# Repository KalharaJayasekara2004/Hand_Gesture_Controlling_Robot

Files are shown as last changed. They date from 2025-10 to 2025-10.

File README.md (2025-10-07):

# Hand Gesture-Controlled Robot with Gripper Expansion


This is a gesture-controlled robot project using ESP32 and MPU6050 IMU, with a gripper expansion. The robot uses two ESP32 boards for transmitter and receiver communication and comes with STL files for the chassis.

## Features
- Gesture control using MPU6050 IMU
- Gripper mechanism for object manipulation
- ESP32-CAM for wireless video streaming
- Transmitter and receiver using ESP32 boards
- Fully 3D-printable chassis

## Components
- ESP32 boards (x2)
- MPU6050 IMU
- TB6612 FNG motor drivers(x2)
- Gripper expansion
- Servo motor for gripper
- ESP32-cam
- Mecanum wheels(x4)
- TT gear motors(x4)
- 3.7V Li-ion batteries(x3)
- Miscellaneous electronics and mechanical parts
- STL files for chassis

## File Structure
- Code- Arduino sketches for transmitter and receiver
- 3D Files - STL files for 3D printing chassis
- Images - Photos of the assembled robot

## Usage
1. Upload the `Transmitter.ino` sketch to the transmitter ESP32.
2. Upload the `Receiver.ino` sketch to the receiver ESP32.
3. Assemble the robot chassis using the STL files.
4. Connect hardware.
5. Power the ESP32 boards and test gestures.

## Author
- Kalhara Jayasekara
- Electrical and Electronic Engineering Undergraduate | University of Peradeniya

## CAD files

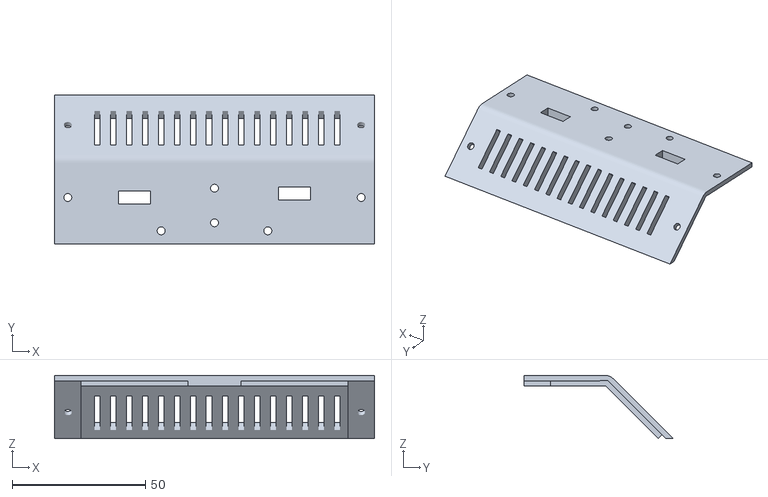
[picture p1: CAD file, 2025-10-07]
front_final.stl
120.0 x 56.0 x 23.7

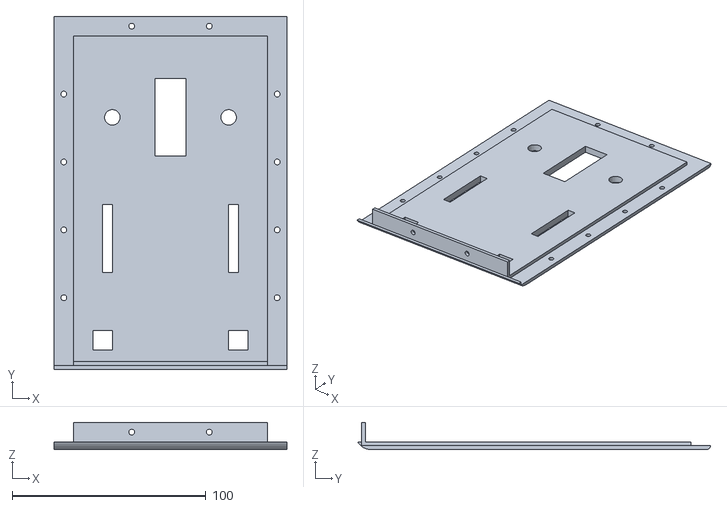
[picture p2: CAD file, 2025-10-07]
top_final.stl
120.0 x 182.0 x 14.0

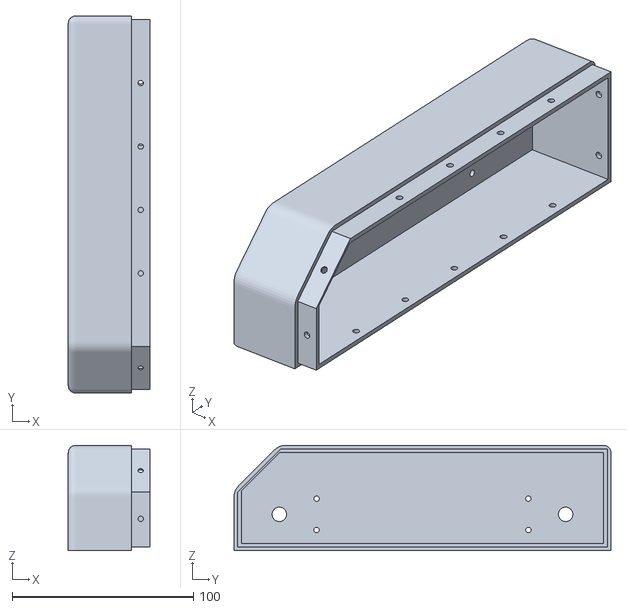
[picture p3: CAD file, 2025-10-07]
Right_side.stl
45.0 x 208.0 x 58.0

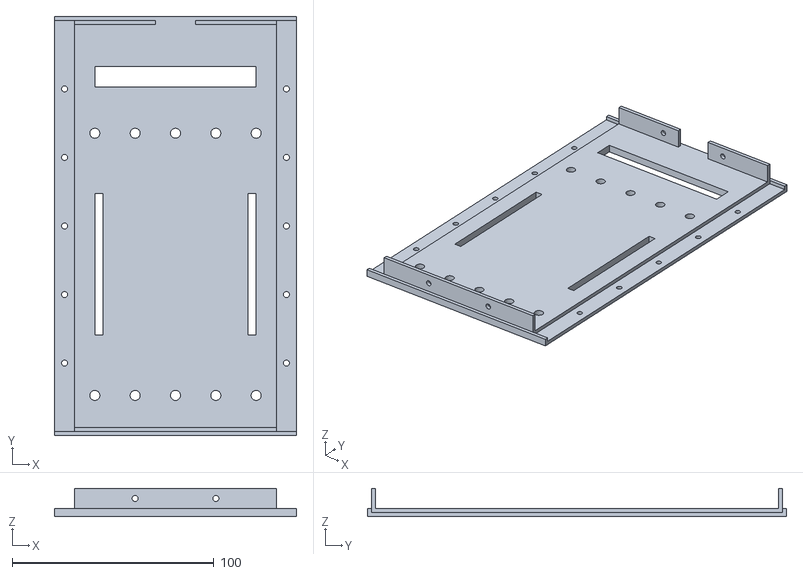
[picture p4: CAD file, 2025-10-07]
bottom_final.stl
120.0 x 208.0 x 14.0

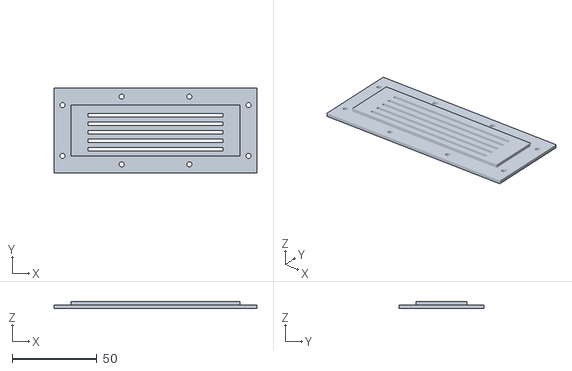
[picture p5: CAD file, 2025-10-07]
back_final.stl
120.0 x 50.0 x 4.00

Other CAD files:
left_side.stl

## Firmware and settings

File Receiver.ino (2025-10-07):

#include <esp_now.h>
#include <WiFi.h>
#include <vector>
#include <ESP32Servo.h>   // Added for servo

#define FORWARD 1
#define BACKWARD 2
#define LEFT 3
#define RIGHT 4
#define FORWARD_LEFT 5
#define FORWARD_RIGHT 6
#define BACKWARD_LEFT 7
#define BACKWARD_RIGHT 8
#define TURN_LEFT 9
#define TURN_RIGHT 10
#define STOP 0

#define BACK_RIGHT_MOTOR 0
#define BACK_LEFT_MOTOR 1
#define FRONT_RIGHT_MOTOR 2
#define FRONT_LEFT_MOTOR 3

// ------------------------ MOTOR PINS ------------------------
struct MOTOR_PINS
{
  int pinIN1;
  int pinIN2;
  int pinEn; 
  int pwmSpeedChannel;
};

std::vector<MOTOR_PINS> motorPins = 
{
  {16, 17, 22, 4},  // BACK_RIGHT_MOTOR
  {18, 19, 23, 5},  // BACK_LEFT_MOTOR
  {26, 27, 14, 6},  // FRONT_RIGHT_MOTOR
  {33, 25, 32, 7},  // FRONT_LEFT_MOTOR
};

#define MAX_MOTOR_SPEED 50
const int PWMFreq = 1000;      // 1 KHz
const int PWMResolution = 8;   // 8-bit PWM

#define SIGNAL_TIMEOUT 1000  // in milliseconds
unsigned long lastRecvTime = 0;

// ------------------------ PACKET DATA ------------------------
typedef struct PacketData
{
  byte xAxisValue;
  byte yAxisValue;
  byte zAxisValue;
  byte logic;     // Added new field for logic
} PacketData;

PacketData receiverData;

// ------------------------ SERVO SETUP ------------------------
Servo myServo;               
#define SERVO_PIN 21          // Servo connected here
int lastLogicState = 0;       // Track last logic state

// ------------------------ CALLBACK ------------------------
void OnDataRecv(const esp_now_recv_info_t *info, const uint8_t *incomingData, int len) 
{
  if (len == 0) return;

  memcpy(&receiverData, incomingData, sizeof(receiverData));

  // Print received values
  Serial.printf("values %d  %d  %d  Logic: %d\n", 
                receiverData.xAxisValue, 
                receiverData.yAxisValue, 
                receiverData.zAxisValue,
                receiverData.logic);

  // ----------------- Servo Logic -----------------

  if (receiverData.logic == 1 && lastLogicState == 0) {
    myServo.write(0);   // move once to 90° when logic changes 0 → 1
  }
  if (receiverData.logic == 0 && lastLogicState == 1) {
    myServo.write(90);    // return once to 0° when logic changes 1 → 0
  }
  lastLogicState = receiverData.logic;

  // ----------------- Movement Logic -----------------
  if (receiverData.xAxisValue < 75 && receiverData.yAxisValue < 75)
    processCarMovement(FORWARD_LEFT);    
  else if (receiverData.xAxisValue > 175 && receiverData.yAxisValue < 75)
    processCarMovement(FORWARD_RIGHT);    
  else if (receiverData.xAxisValue < 75 && receiverData.yAxisValue > 175)
    processCarMovement(BACKWARD_LEFT);    
  else if (receiverData.xAxisValue > 175 && receiverData.yAxisValue > 175)
    processCarMovement(BACKWARD_RIGHT);  
  else if (receiverData.zAxisValue > 175)
    processCarMovement(TURN_RIGHT);
  else if (receiverData.zAxisValue < 75)
    processCarMovement(TURN_LEFT);
  else if (receiverData.yAxisValue < 75)
    processCarMovement(FORWARD);  
  else if (receiverData.yAxisValue > 175)
    processCarMovement(BACKWARD);     
  else if (receiverData.xAxisValue > 175)
    processCarMovement(RIGHT);   
  else if (receiverData.xAxisValue < 75)
    processCarMovement(LEFT);    
  else
    processCarMovement(STOP);     

  lastRecvTime = millis();   
}

// ------------------------ MOTOR CONTROL ------------------------
void processCarMovement(int inputValue)
{
  switch(inputValue)
  {
    case FORWARD:
      rotateMotor(FRONT_RIGHT_MOTOR, MAX_MOTOR_SPEED);
      rotateMotor(BACK_RIGHT_MOTOR, MAX_MOTOR_SPEED);
      rotateMotor(FRONT_LEFT_MOTOR, MAX_MOTOR_SPEED);
      rotateMotor(BACK_LEFT_MOTOR, MAX_MOTOR_SPEED);                  
      break;

    case BACKWARD:
      rotateMotor(FRONT_RIGHT_MOTOR, -MAX_MOTOR_SPEED);
      rotateMotor(BACK_RIGHT_MOTOR, -MAX_MOTOR_SPEED);
      rotateMotor(FRONT_LEFT_MOTOR, -MAX_MOTOR_SPEED);
      rotateMotor(BACK_LEFT_MOTOR, -MAX_MOTOR_SPEED);   
      break;

    case LEFT:
      rotateMotor(FRONT_RIGHT_MOTOR, MAX_MOTOR_SPEED);
      rotateMotor(BACK_RIGHT_MOTOR, -MAX_MOTOR_SPEED);
      rotateMotor(FRONT_LEFT_MOTOR, -MAX_MOTOR_SPEED);
      rotateMotor(BACK_LEFT_MOTOR, MAX_MOTOR_SPEED);   
      break;

    case RIGHT:
      rotateMotor(FRONT_RIGHT_MOTOR, -MAX_MOTOR_SPEED);
      rotateMotor(BACK_RIGHT_MOTOR, MAX_MOTOR_SPEED);
      rotateMotor(FRONT_LEFT_MOTOR, MAX_MOTOR_SPEED);
      rotateMotor(BACK_LEFT_MOTOR, -MAX_MOTOR_SPEED);  
      break;

    case FORWARD_LEFT:
      rotateMotor(FRONT_RIGHT_MOTOR, MAX_MOTOR_SPEED);
      rotateMotor(BACK_RIGHT_MOTOR, 0);
      rotateMotor(FRONT_LEFT_MOTOR, 0);
      rotateMotor(BACK_LEFT_MOTOR, MAX_MOTOR_SPEED);  
      break;

    case FORWARD_RIGHT:
      rotateMotor(FRONT_RIGHT_MOTOR, 0);
      rotateMotor(BACK_RIGHT_MOTOR, MAX_MOTOR_SPEED);
      rotateMotor(FRONT_LEFT_MOTOR, MAX_MOTOR_SPEED);
      rotateMotor(BACK_LEFT_MOTOR, 0);  
      break;

    case BACKWARD_LEFT:
      rotateMotor(FRONT_RIGHT_MOTOR, 0);
      rotateMotor(BACK_RIGHT_MOTOR, -MAX_MOTOR_SPEED);
      rotateMotor(FRONT_LEFT_MOTOR, -MAX_MOTOR_SPEED);
      rotateMotor(BACK_LEFT_MOTOR, 0);   
      break;

    case BACKWARD_RIGHT:
      rotateMotor(FRONT_RIGHT_MOTOR, -MAX_MOTOR_SPEED);
      rotateMotor(BACK_RIGHT_MOTOR, 0);
      rotateMotor(FRONT_LEFT_MOTOR, 0);
      rotateMotor(BACK_LEFT_MOTOR, -MAX_MOTOR_SPEED);   
      break;

    case TURN_LEFT:
      rotateMotor(FRONT_RIGHT_MOTOR, MAX_MOTOR_SPEED);
      rotateMotor(BACK_RIGHT_MOTOR, MAX_MOTOR_SPEED);
      rotateMotor(FRONT_LEFT_MOTOR, -MAX_MOTOR_SPEED);
      rotateMotor(BACK_LEFT_MOTOR, -MAX_MOTOR_SPEED);  
      break;

    case TURN_RIGHT:
      rotateMotor(FRONT_RIGHT_MOTOR, -MAX_MOTOR_SPEED);
      rotateMotor(BACK_RIGHT_MOTOR, -MAX_MOTOR_SPEED);
      rotateMotor(FRONT_LEFT_MOTOR, MAX_MOTOR_SPEED);
      rotateMotor(BACK_LEFT_MOTOR, MAX_MOTOR_SPEED);   
      break;

    case STOP:
    default:
      rotateMotor(FRONT_RIGHT_MOTOR, 0);
      rotateMotor(BACK_RIGHT_MOTOR, 0);
      rotateMotor(FRONT_LEFT_MOTOR, 0);
      rotateMotor(BACK_LEFT_MOTOR, 0);    
      break;
  }
}

// ------------------------ ROTATE MOTOR ------------------------
void rotateMotor(int motorNumber, int motorSpeed)
{
  if (motorSpeed < 0)
  {
    digitalWrite(motorPins[motorNumber].pinIN1, LOW);
    digitalWrite(motorPins[motorNumber].pinIN2, HIGH);    
  }
  else if (motorSpeed > 0)
  {
    digitalWrite(motorPins[motorNumber].pinIN1, HIGH);
    digitalWrite(motorPins[motorNumber].pinIN2, LOW);       
  }
  else
  {
    digitalWrite(motorPins[motorNumber].pinIN1, LOW);
    digitalWrite(motorPins[motorNumber].pinIN2, LOW);      
  }
  
  ledcWrite(motorPins[motorNumber].pinEn, abs(motorSpeed));
}

// ------------------------ SETUP PINS ------------------------
void setUpPinModes()
{
  for (int i = 0; i < motorPins.size(); i++)
  {
    pinMode(motorPins[i].pinIN1, OUTPUT);
    pinMode(motorPins[i].pinIN2, OUTPUT);

    ledcAttach(motorPins[i].pinEn, PWMFreq, PWMResolution);

    rotateMotor(i, 0);
  }
}

// ------------------------ SETUP ------------------------
void setup() 
{
     // Read logic signal
  myServo.attach(SERVO_PIN);
  Serial.begin(115200);

  setUpPinModes();

  // Setup servo
  //myServo.attach(SERVO_PIN, 500, 2400);
  myServo.write(0);  // start at 0°

  WiFi.mode(WIFI_STA);

  if (esp_now_init() != ESP_OK) 
  {
    Serial.println("Error initializing ESP-NOW");
    return;
  }

  esp_now_register_recv_cb(OnDataRecv);
}
 
// ------------------------ LOOP ------------------------
void loop() 
{
  if (millis() - lastRecvTime > SIGNAL_TIMEOUT) 
  {
    processCarMovement(STOP); 
  }
}

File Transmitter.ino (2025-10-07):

#include <esp_now.h>
#include <WiFi.h>

//These are needed for MPU
#include "I2Cdev.h"
#include "MPU6050_6Axis_MotionApps20.h"
#if I2CDEV_IMPLEMENTATION == I2CDEV_ARDUINO_WIRE
#include "Wire.h"
#endif

// MPU control/status vars
MPU6050 mpu;
bool dmpReady = false;  // set true if DMP init was successful
uint8_t devStatus;      // return status after each device operation (0 = success, !0 = error)
uint8_t fifoBuffer[64]; // FIFO storage buffer
Quaternion q;           // [w, x, y, z] quaternion container
VectorFloat gravity;    // [x, y, z] gravity vector
float ypr[3];           // [yaw, pitch, roll] yaw/pitch/roll container and gravity vector

// RECEIVER MAC Address
uint8_t receiverMacAddress[] = {0xAC, 0x15, 0x18, 0xED, 0x9D, 0x90};  //00:4B:12:34:32:08

// Define input pin
#define INPUT_PIN 32  

typedef struct PacketData 
{
  byte xAxisValue;
  byte yAxisValue;
  byte zAxisValue;  
  byte logicValue;   // New field for HIGH/LOW input
} PacketData;
PacketData data;

esp_now_peer_info_t peerInfo;

// Updated callback for ESP-IDF v5.x
void OnDataSent(const esp_now_send_info_t *info, esp_now_send_status_t status)
{
  char macStr[18];
  snprintf(macStr, sizeof(macStr), "%02X:%02X:%02X:%02X:%02X:%02X",
           info->des_addr[0], info->des_addr[1], info->des_addr[2],
           info->des_addr[3], info->des_addr[4], info->des_addr[5]);

  Serial.print("Last Packet Sent to: ");
  Serial.println(macStr);
  Serial.println(status == ESP_NOW_SEND_SUCCESS ? "Delivery Success" : "Delivery Fail");
}


void setupMPU()
{
  #if I2CDEV_IMPLEMENTATION == I2CDEV_ARDUINO_WIRE
      Wire.begin();
      Wire.setClock(400000); // 400kHz I2C clock
  #elif I2CDEV_IMPLEMENTATION == I2CDEV_BUILTIN_FASTWIRE
      Fastwire::setup(400, true);
  #endif

  mpu.initialize();
  devStatus = mpu.dmpInitialize();
  if (devStatus == 0) 
  {
      mpu.CalibrateAccel(6);
      mpu.CalibrateGyro(6);
      mpu.setDMPEnabled(true);
      dmpReady = true;
  } 
}

void setup()
{
  Serial.begin(115200);
  WiFi.mode(WIFI_STA);

  // Init ESP-NOW
  if (esp_now_init() != ESP_OK) 
  {
    Serial.println("Error initializing ESP-NOW");
    return;
  }
  else
  {
    Serial.println("Success: Initialized ESP-NOW");
  }

  esp_now_register_send_cb(OnDataSent);
  
  // Register peer
  memcpy(peerInfo.peer_addr, receiverMacAddress, 6);
  peerInfo.channel = 0;  
  peerInfo.encrypt = false;
  
  if (esp_now_add_peer(&peerInfo) != ESP_OK)
  {
    Serial.println("Failed to add peer");
    return;
  }
  else
  {
    Serial.println("Success: Added peer");
  }   

  // Set up MPU6050 sensor
  setupMPU();  

  // Set input pin mode
  pinMode(INPUT_PIN, INPUT);
}

void loop() 
{
  if (!dmpReady) return;

  if (mpu.dmpGetCurrentFIFOPacket(fifoBuffer)) 
  {  
    mpu.dmpGetQuaternion(&q, fifoBuffer);
    mpu.dmpGetGravity(&gravity, &q);
    mpu.dmpGetYawPitchRoll(ypr, &q, &gravity);

    int xAxisValue = constrain(ypr[2] * 180/M_PI, -90, 90);
    int yAxisValue = constrain(ypr[1] * 180/M_PI, -90, 90);
    int zAxisValue = constrain(ypr[0] * 180/M_PI, -90, 90);    

    data.xAxisValue = map(xAxisValue, -90, 90, 0, 254); 
    data.yAxisValue = map(yAxisValue, -90, 90, 0, 254);
    data.zAxisValue = map(zAxisValue, -90, 90, 0, 254);    

    // Read logic input (HIGH or LOW)
    data.logicValue = digitalRead(INPUT_PIN);  

    esp_err_t result = esp_now_send(receiverMacAddress, (uint8_t *) &data, sizeof(data));

    // Print for debugging
    String inputData = "values " + String(xAxisValue) + "  " + String(yAxisValue) + "  " + 
                       String(zAxisValue) + "  Logic: " + String(data.logicValue);
    Serial.println(inputData);

    delay(50);            
  }
}
